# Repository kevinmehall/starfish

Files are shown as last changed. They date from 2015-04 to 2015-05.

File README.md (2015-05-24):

This tiny board provides a 12-pin Pmod port, controlled over USB. [Pmod](http://www.digilentinc.com/Pmods/Digilent-Pmod_%20Interface_Specification.pdf) is a standard pinout for SPI, I2C, UART, and GPIO on a 6 or 12 pin connector, with over 100 modules available from several companies. 

Level shifters and a digitally-controlled voltage regulator allow it to operate at 1.2 - 5V IO levels. 

Key components:

  * [Atmel SAMD21](http://www.atmel.com/Images/Atmel-42181-SAM-D21_Datasheet.pdf) - Cortex M0+ microcontroller
  * [Fairchild FXMAR2104](https://www.fairchildsemi.com/datasheets/FX/FXMAR2104.pdf) - IO level shifter

Firmware bringup is in progress. It will work with the [Tessel 2 JavaScript API](https://github.com/tessel/t2-firmware) and [Signalspec](http://signalspec.org).

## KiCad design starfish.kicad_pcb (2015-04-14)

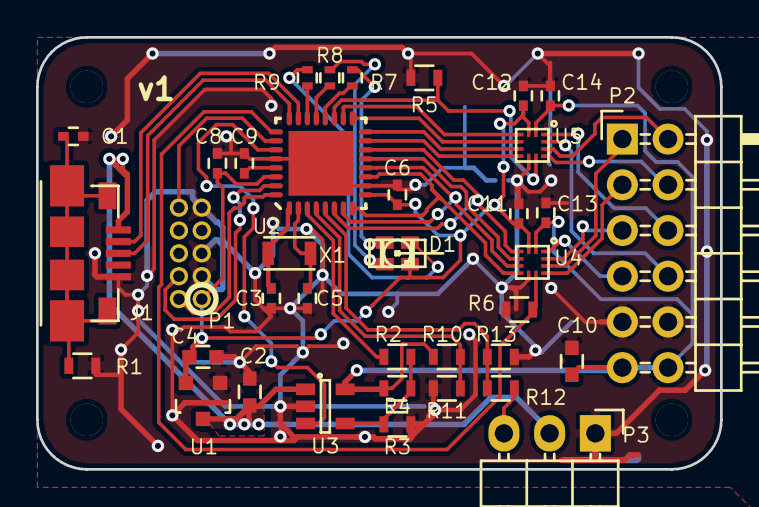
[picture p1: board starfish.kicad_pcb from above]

Board: 2 copper layers, 38.0 x 24.0 mm, 37 parts (0 on the bottom side), 43 nets.

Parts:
C1, C3, C5: 10pF; C_0402
C2, C4, C10: 1uF; C_0603
C6, C8, C9, C11, C12, C13, C14: 100nF; C_0402
D1: LED-RGB-COMMON-ANODE; LED-1206-RGB
J1: microUSB; MICRO-USB-10104111
P1: CONN_02X05; CONN_02x05_0.05in
P2: CONN_6X2; Pin_Header_Angled_2x06
P3: CONN_3; Pin_Header_Angled_1x03
R1, R2, R10, R12: 47k; R_0603
R3, R4, R5, R6, R11, R13: 27k; R_0603
R7, R8, R9: 120; R_0402
U1: AP2120N; SOT-23
U2: SAMD21E15A-MU; QFP32
U3: TPS73101; SOT-23-5
U4, U5: FXMAR2104; UMLP-12
X1: CRYSTAL; FC-135

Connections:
+3V3: C4.1, C6.1, C8.1, C11.1, C12.1, D1.4, P1.1, U1.2, U2.9, U2.30, U4.2, U5.2
+5V: C2.1, J1.1, P3.2, U1.3, U3.1
/ADC: R12.2, R13.1, U2.5
/ADC_IN: P3.3, R12.1
/ADC_P: R10.2, R11.1, U2.4
/DAC: R4.1, U2.3
/EN_P: U2.27, U3.3
/EN_X: R6.1, U2.25, U4.8
/EN_Y: R5.1, U2.19, U5.8
/LED_B: R9.2, U2.22
/LED_G: R8.2, U2.21
/LED_R: R7.2, U2.20
/SWCLK: P1.4, U2.31
/SWDIO: P1.2, U2.32
/USB+: J1.3, U2.24
/USB-: J1.2, U2.23
/X1: P2.1, U4.10
/X1M: U2.7, U2.12, U4.5
/X2: P2.3, U4.9
/X2M: U2.8, U2.11, U4.6
/X3: P2.5, U4.11
/X3M: U2.13, U4.4
/X4: P2.7, U4.12
/X4M: U2.6, U2.14, U4.3
/Y1: P2.2, U5.10
/Y1M: U2.16, U5.5
/Y2: P2.4, U5.9
/Y2M: U2.15, U5.6
/Y3: P2.6, U5.12
/Y3M: U2.18, U5.3
/Y4: P2.8, U5.11
/Y4M: U2.17, U5.4
/~RESET: P1.10, U2.26
GND: C1.2, C2.2, C3.2, C4.2, C5.2, C6.2, C8.2, C9.2, C10.2, C11.2, C12.2, C13.2, C14.2, J1.5, P1.3, P1.5, P1.9, P2.9, P2.10, P3.1, R1.2, R3.2, R5.2, R6.2, R11.2, R13.2, U1.1, U2.0, U2.10, U2.28, U3.2, U4.7, U5.7
unnamed: C1.1, J1.0, R1.1
unnamed: C3.1, U2.1, X1.1
unnamed: C5.1, U2.2, X1.2
unnamed: C9.1, U2.29
unnamed: D1.1, R9.1
unnamed: D1.2, R7.1
unnamed: D1.3, R8.1
unnamed: R2.2, R3.1, R4.2, U3.4
VAA: C10.1, C13.1, C14.1, P2.11, P2.12, R2.1, R10.1, U3.5, U4.1, U5.1

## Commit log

2015-04-14 Fully routed
    [starfish.kicad_pcb, starfish.sch]
2015-04-14 Add pin mux notes
